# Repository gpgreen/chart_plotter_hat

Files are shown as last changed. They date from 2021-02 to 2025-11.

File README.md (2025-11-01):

# Chart Plotter Hat

KiCad design for Raspberry Pi Hat. Provides power and switch on/off
for the board. A total of 1.2A is provided for use by the
RaspberryPi. Also some connectors for GPS, barometric sensor, and ADC
measurements. Provides 12V power for a remote video board which is
switched at the same time as the Raspberry Pi. Contains a MCP2515 CAN
Controller and MCP2551 CAN transceiver for access to CAN bus. The
transceiver is isolated from the rest of the board. Has a
Qwiic connector that allows I2C
devices to be connected to the Raspberry Pi.

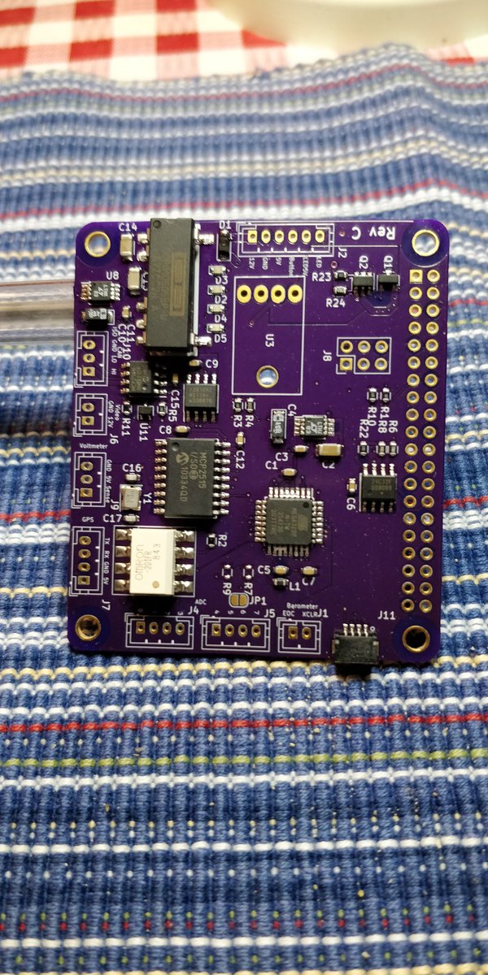
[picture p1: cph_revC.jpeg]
Finished


## Functions

1. Onboard ATmega328P
2. 1.2A DC power for RaspberryPi provided by
   AdaFruit MPM3610 5V Buck Converter Breakout
3. Video board power (12V) controlled by solid state relay G3VM-201FR
4. Serial Connector for GPS with 5V power, routed to Raspberry Pi Uart1.
5. 2 connectors with 4 pins each routed to adc pins on ATmega328P
6. Qwiic Connector, routed to I2C1 on Raspberry Pi
7. eeprom & power isolation as required by Raspberry Pi hat spec
8. Onboard 3.3V power for the ATmega328P.
9. SPI on ATmega328P routed to the Raspberry Pi SPI0 for communication
10. MCP2515 CAN network device, controlled by Raspberry Pi on SPI1
11. CAN is isolated to meet specs of NMEA 2000.
12. Connector for external voltmeter, or see 13.
13. Optional 12V voltage divider routed to ADC7 on the ATmega328P. This option is
    selected by a solder jumper.

## Firmware

There are 2 projects for the firmware. One is using `C`, the other `Rust`.
 - C firmware for the
onboard ATmega328P using avr-gcc and avr-libc.
 - Rust firmware.

The Rust firmware is still experimental. There are a number of
compiler bugs for the 8-bit AVR's yet.

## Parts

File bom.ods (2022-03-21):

D | Chart Plotter Hat
Rev | C
Design | /home/ggreen/cad/kicad/chart_plotter_hat/chart_plotter_hat.sch
Date
Components
ref | value | footprint | libsource | lib | part | description | sheetpath | names | tstamps | tstamp | datasheet | field | name
C1 | .1uF | Capacitors_SMD:C_0603 |  | Device | C | Unpolarized capacitor |  | / | / | 5FEBF281 | ~
C2 | 1uF | Capacitors_SMD:C_1206 |  | Device | C | Unpolarized capacitor |  | / | / | 5FE6DD6F | ~ | 25V | Voltage
C3 | .01uF | Capacitors_SMD:C_0603 |  | Device | C | Unpolarized capacitor |  | / | / | 5FE6EE51 | ~
C4 | 10uF | Capacitors_Tantalum_SMD:CP_Tantalum_Case-A_EIA-3216-18_Reflow |  | Device | CP | Polarized capacitor |  | / | / | 5FE95833 | ~
C5 | .1uF | Capacitors_SMD:C_0603 |  | Device | C | Unpolarized capacitor |  | / | / | 5FFED6E8 | ~
C6 | .1uF | Capacitors_SMD:C_0603 |  | Device | C | Unpolarized capacitor |  | / | / | 5FDB0A51 | ~
C7 | .1uF | Capacitors_SMD:C_0603 |  | Device | C | Unpolarized capacitor |  | / | / | 5FE38A21 | ~
C8 | .1uF | Capacitors_SMD:C_0603 |  | Device | C | Unpolarized capacitor |  | / | / | 0 | ~
C9 | .1uF | Capacitors_SMD:C_0603 |  | Device | C | Unpolarized capacitor |  | / | / | 615A87B3 | ~
C10 | 10uF | Capacitors_Tantalum_SMD:CP_Tantalum_Case-A_EIA-3216-18_Reflow |  | Device | CP | Polarized capacitor |  | / | / | 61359206 | ~
C11 | .01uF | Capacitors_SMD:C_0603 |  | Device | C | Unpolarized capacitor |  | / | / | 61313B3B | ~
C12 | .1uF | Capacitors_SMD:C_0603 |  | Device | C | Unpolarized capacitor |  | / | / | 609D50D2 | ~
C13 | 1uF | Capacitors_SMD:C_1206 |  | Device | C | Unpolarized capacitor |  | / | / | 614D291D | ~
C14 | 2.2uF | Capacitors_SMD:C_1206 |  | Device | C | Unpolarized capacitor |  | / | / | 61485000000000 | ~
C15 | .1uF | Capacitors_SMD:C_0603 |  | Device | C | Unpolarized capacitor |  | / | / | 609D9249 | ~
C16 | 18pF | Capacitors_SMD:C_0603 |  | Device | C | Unpolarized capacitor |  | / | / | 609DC300 | ~
C17 | 18pF | Capacitors_SMD:C_0603 |  | Device | C | Unpolarized capacitor |  | / | / | 609DCBED | ~
D1 | PMEG3020EH | Diodes_SMD:D_SOD-123 |  | Diode | PMEG3020EH | 30V, 2A ultra low Vf MEGA Schottky barrier rectifier, SOD-123F |  | / | / | 6019111C | https://assets.nexperia.com/documents/data-sheet/PMEG3020EH_EJ.pdf
D2 | RED | Diodes_SMD:D_0603 |  | Device | LED | Light emitting diode |  | / | / | 616837C9 | ~
D3 | RED | Diodes_SMD:D_0603 |  | Device | LED | Light emitting diode |  | / | / | 616BC4CF | ~
D4 | RED | Diodes_SMD:D_0603 |  | Device | LED | Light emitting diode |  | / | / | 616DB45B | ~
D5 | GRN | Diodes_SMD:D_0603 |  | Device | LED | Light emitting diode |  | / | / | 6180FD86 | ~
H1 | 3mm_Mounting_Hole | project_footprints:NPTH_3mm_ID |  | Mechanical | MountingHole | Mounting Hole without connection |  | / | / | 5834BC4A | ~
H2 | 3mm_Mounting_Hole | project_footprints:NPTH_3mm_ID |  | Mechanical | MountingHole | Mounting Hole without connection |  | / | / | 5834BCDF | ~ | 25V | Voltage
H3 | 3mm_Mounting_Hole | project_footprints:NPTH_3mm_ID |  | Mechanical | MountingHole | Mounting Hole without connection |  | / | / | 5834BD62 | ~
H4 | 3mm_Mounting_Hole | project_footprints:NPTH_3mm_ID |  | Mechanical | MountingHole | Mounting Hole without connection |  | / | / | 5834BDED | ~
J1 | JST PH | Connectors_JST:JST_PH_B2B-PH-K_02x2.00mm_Straight |  | Connector_Generic | Conn_01x02 | Generic connector, single row, 01x02, script generated (kicad-library-utils/schlib/autogen/connector/) |  | / | / | 61554C23 | ~
J2 | JST PH | Connectors_JST:JST_PH_B6B-PH-K_06x2.00mm_Straight |  | Connector_Generic | Conn_01x06 | Generic connector, single row, 01x06, script generated (kicad-library-utils/schlib/autogen/connector/) |  | / | / | 616B530A | ~
J3 | 40HAT | Connector_PinSocket_2.54mm:PinSocket_2x20_P2.54mm_Vertical |  | raspberrypi_hat | OX40HAT |  |  | / | / | 58DFC771 | ~
J4 | JST PH | Connectors_JST:JST_PH_B4B-PH-K_04x2.00mm_Straight |  | Connector_Generic | Conn_01x04 | Generic connector, single row, 01x04, script generated (kicad-library-utils/schlib/autogen/connector/) |  | / | / | 5FFD0767 | ~ | 25V | Voltage
J5 | JST PH | Connectors_JST:JST_PH_B4B-PH-K_04x2.00mm_Straight |  | Connector_Generic | Conn_01x04 | Generic connector, single row, 01x04, script generated (kicad-library-utils/schlib/autogen/connector/) |  | / | / | 5FFD2002 | ~
J6 | JST PH | Connectors_JST:JST_PH_B2B-PH-K_02x2.00mm_Straight |  | Connector_Generic | Conn_01x02 | Generic connector, single row, 01x02, script generated (kicad-library-utils/schlib/autogen/connector/) |  | / | / | 5FEFCBF8 | ~
J7 | JST PH | Connectors_JST:JST_PH_B4B-PH-K_04x2.00mm_Straight |  | Connector_Generic | Conn_01x04 | Generic connector, single row, 01x04, script generated (kicad-library-utils/schlib/autogen/connector/) |  | / | / | 5FD96B98 | ~
J8 | Conn_02x03_Odd_Even | Pin_Headers:Pin_Header_Straight_2x03_Pitch2.54mm |  | Connector_Generic | Conn_02x03_Odd_Even | Generic connector, double row, 02x03, odd/even pin numbering scheme (row 1 odd numbers, row 2 even numbers), script generated (kicad-library-utils/schlib/autogen/connector/) |  | / | / | 5FDFC5AF | ~
J9 | JST PH | Connectors_JST:JST_PH_B3B-PH-K_03x2.00mm_Straight |  | Connector_Generic | Conn_01x03 | Generic connector, single row, 01x03, script generated (kicad-library-utils/schlib/autogen/connector/) |  | / | / | 5FF77E36 | ~
J10 | JST PH | Connectors_JST:JST_PH_B3B-PH-K_03x2.00mm_Straight |  | Connector_Generic | Conn_01x03 | Generic connector, single row, 01x03, script generated (kicad-library-utils/schlib/autogen/connector/) |  | / | / | 617535000000000 | ~
J11 | Qwiic | Connectors_JST:JST_SH_BM04B-SRSS-TB_04x1.00mm_Straight |  | Connector_Generic | Conn_01x04 | Generic connector, single row, 01x04, script generated (kicad-library-utils/schlib/autogen/connector/) |  | / | / | 615837CF | ~
JP1 | SolderJumper_2_Open | CustomComponents:SolderJumper-2_P1.3mm_Open_RoundedPad1.0x1.5mm |  | Jumper | SolderJumper_2_Open | Solder Jumper, 2-pole, open |  | / | / | 601AB575 | ~
L1 | 10uH | Capacitors_SMD:C_0603 |  | Device | L_Small | Inductor, small symbol |  | / | / | 5FF4C159 | ~
Q1 | DMG2305UX | Package_TO_SOT_SMD:SOT-23 |  | raspberrypi_hat | DMG2305UX | Transistor P-MOSFET |  | / | / | 58E14EB1 | ~ | SML-D12U8WT86
Q2 | DMMT5401 | Package_TO_SOT_SMD:SOT-23-6 |  | raspberrypi_hat | DMMT5401 | PNP Matched Transistor Pair |  | / | / | 58E1538B | ~
R1 | 10K | Resistors_SMD:R_0603 |  | Device | R | Resistor |  | / | / | 5FEF7011
R2 | 1.6K | Resistors_SMD:R_0603 |  | Device | R | Resistor |  | / | / | 5FF8607A | ~
R3 | 390 | Resistors_SMD:R_0603 |  | Device | R | Resistor |  | / | / | 616854F3 | ~
R4 | 220 | Resistors_SMD:R_0603 |  | Device | R | Resistor |  | / | / | 616BC4C9 | https://toshiba.semicon-storage.com/info/docget.jsp?did=12660&prodName=TLP3543
R5 | 390 | Resistors_SMD:R_0603 |  | Device | R | Resistor |  | / | / | 616DB455 | http://ww1.microchip.com/downloads/en/devicedoc/21667d.pdf
R6 | 3.9K | Resistors_SMD:R_0603 |  | Device | R | Resistor |  | / | / | 0 | ~
R7 | 39K | Resistors_SMD:R_0603 |  | Device | R | Resistor |  | / | / | 5FF886A6 | ~
R8 | 3.9K | Resistors_SMD:R_0603 |  | Device | R | Resistor |  | / | / | 0 | ~
R9 | 12K | Resistors_SMD:R_0603 |  | Device | R | Resistor |  | / | / | 5FF8821A | ~ | SML-D12FWT86
R10 | 10K | Resistors_SMD:R_0603 |  | Device | R | Resistor |  | / | / | 5FF805D9 | ~
R11 | 300 | Resistors_SMD:R_0603 |  | Device | R | Resistor |  | / | / | 61810910 | http://ww1.microchip.com/downloads/en/DeviceDoc/ATmega328_P%20AVR%20MCU%20with%20picoPower%20Technology%20Data%20Sheet%2040001984A.pdf
R22 | 10K | Resistors_SMD:R_0603 |  | Device | R | Resistor |  | / | / | 58E19E51 | ~
R23 | 10K | Resistors_SMD:R_0603 |  | Device | R | Resistor |  | / | / | 0 | ~
R24 | 47K | Resistors_SMD:R_0603 |  | Device | R | Resistor |  | / | / | 58E158A1 | ~
U1 | ATmega328P-AU | Housings_QFP:TQFP-32_7x7mm_Pitch0.8mm |  | MCU_Microchip_ATmega | ATmega328P-AU | 20MHz, 32kB Flash, 2kB SRAM, 1kB EEPROM, TQFP-32 |  | / | / | 5FD67BE6 | http://ww1.microchip.com/downloads/en/DeviceDoc/ATmega328_P%20AVR%20MCU%20with%20picoPower%20Technology%20Data%20Sheet%2040001984A.pdf
U2 | CAT24C32 | Package_SOIC:SOIC-8_3.9x4.9mm_P1.27mm |  | raspberrypi_hat | CAT24C32 | I2C Serial EEPROM 32Kb |  | / | / | 58E1713F | ~
U3 | MPM3610-5.0-adafruit | CustomComponents:Adafruit_MPM3610 |  | adafruit | MPM3610-adafruit |  |  | / | / | 5FD6743F | ~
U4 | LT1762EMS8-3.3 | Housings_SSOP:MSOP-8_3x3mm_Pitch0.65mm |  | Regulator_Linear | LT1762 | 150mA, Adjustable, Low Noise, Micropower LDO Regulator, MSOP-8 |  | / | / | 5FE414E2 | https://www.analog.com/media/en/technical-documentation/data-sheets/LT1762.pdf
U5 | G3VM-201FR | Housings_DIP:DIP-8_W8.89mm_SMDSocket_LongPads |  | CustomComponents | G3VM-201FR | Photo MOSFET optically coupled, ON 4A, 50mohm, OFF state 20V, Isolation 2500 VRMS, DIP-6 |  | / | / | 5FEC1F34 | https://toshiba.semicon-storage.com/info/docget.jsp?did=12660&prodName=TLP3543
U6 | MCP2515-xSO | Housings_SOIC:SOIC-18W_7.5x11.6mm_Pitch1.27mm |  | Interface_CAN_LIN | MCP2515-xSO | Stand-Alone CAN Controller with SPI Interface, SOIC-18 |  | / | / | 60A70B0A | http://ww1.microchip.com/downloads/en/DeviceDoc/21801e.pdf
U7 | MCP2551-I-SN | Housings_SOIC:SOIC-8_3.9x4.9mm_Pitch1.27mm |  | Interface_CAN_LIN | MCP2551-I-SN | High-Speed CAN Transceiver, 1Mbps, 5V supply, SOIC-8 |  | / | / | 608CD80B | http://ww1.microchip.com/downloads/en/devicedoc/21667d.pdf
U8 | LT1762EMS8-5 | Housings_SSOP:MSOP-8_3x3mm_Pitch0.65mm |  | CustomComponents | LT1762-MS8 | Low Noise LDO |  | / | / | 612AA917 | ~
U9 | ADuM1281CRZ | Housings_SOIC:SOIC-8_3.9x4.9mm_Pitch1.27mm |  | Isolator | ADuM1201BR | Dual-Channel Digital Isolator, 10Mbps 50ns, bidirectional communication, 3V/5V level translation, SOIC-8 |  | / | / | 61231790 | https://www.analog.com/static/imported-files/data_sheets/ADuM1200_1201.pdf
U10 | DCP010505BP-U | CustomComponents:DCP01B_SO_7_14 |  | CustomComponents | DCP01B |  |  | / | / | 61341169 | ~
U11 | VCAN26A2 | TO_SOT_Packages_SMD:SOT-323_SC-70 |  | CustomComponents | VCAN26A2 | Bidirectional Symmetrical Low Capacitance Dual-Line ESD Protection Diode |  | / | / | 613DD013 | https://www.vishay.com/docs/85894/vcan26a2-03g.pdf | 25V | Voltage
Y1 | 16MHz | Crystals:Crystal_SMD_TXC_7M-4pin_3.2x2.5mm |  | Device | Crystal_GND24_Small | Four pin crystal, GND on pins 2 and 4, small symbol |  | / | / | 6085E13C | ~

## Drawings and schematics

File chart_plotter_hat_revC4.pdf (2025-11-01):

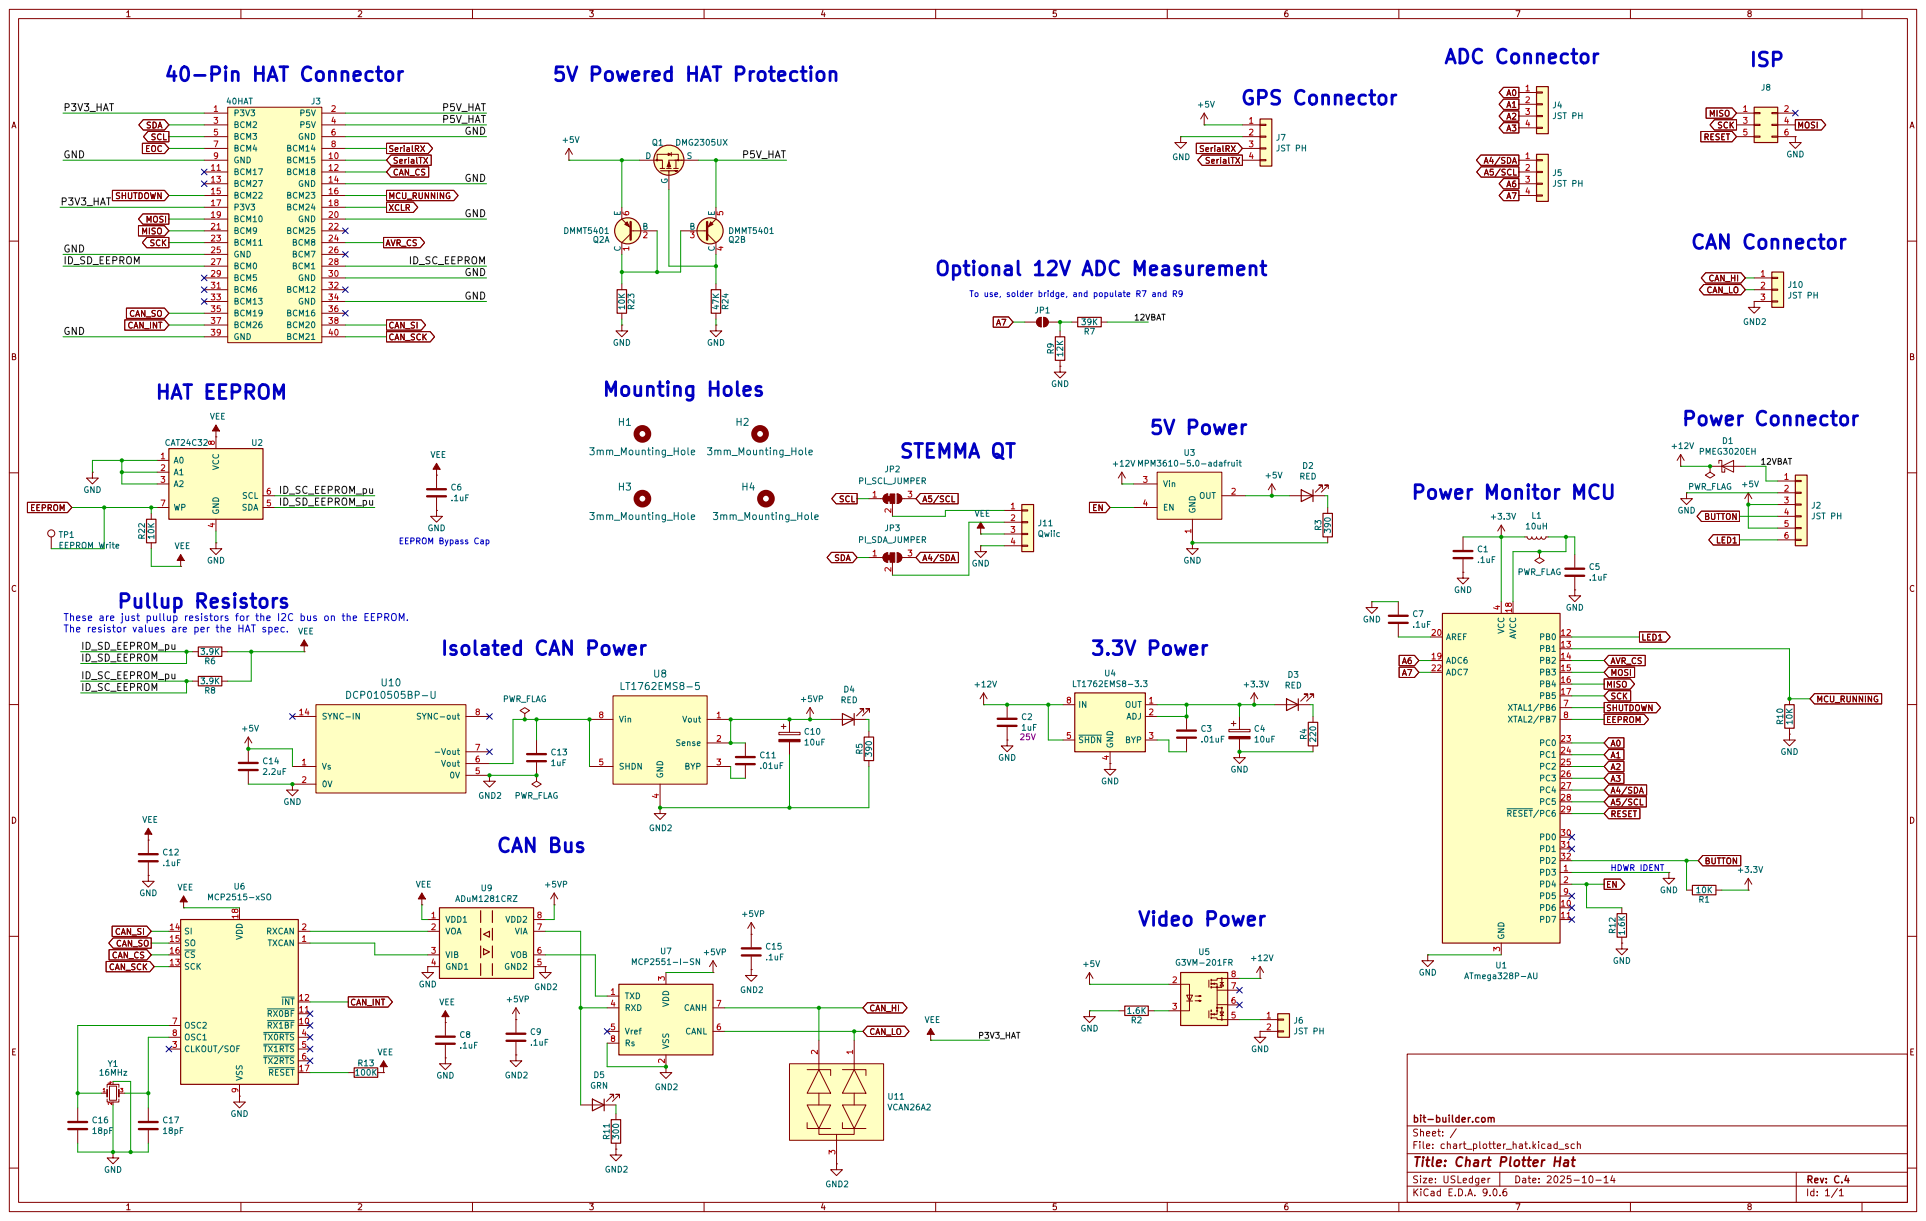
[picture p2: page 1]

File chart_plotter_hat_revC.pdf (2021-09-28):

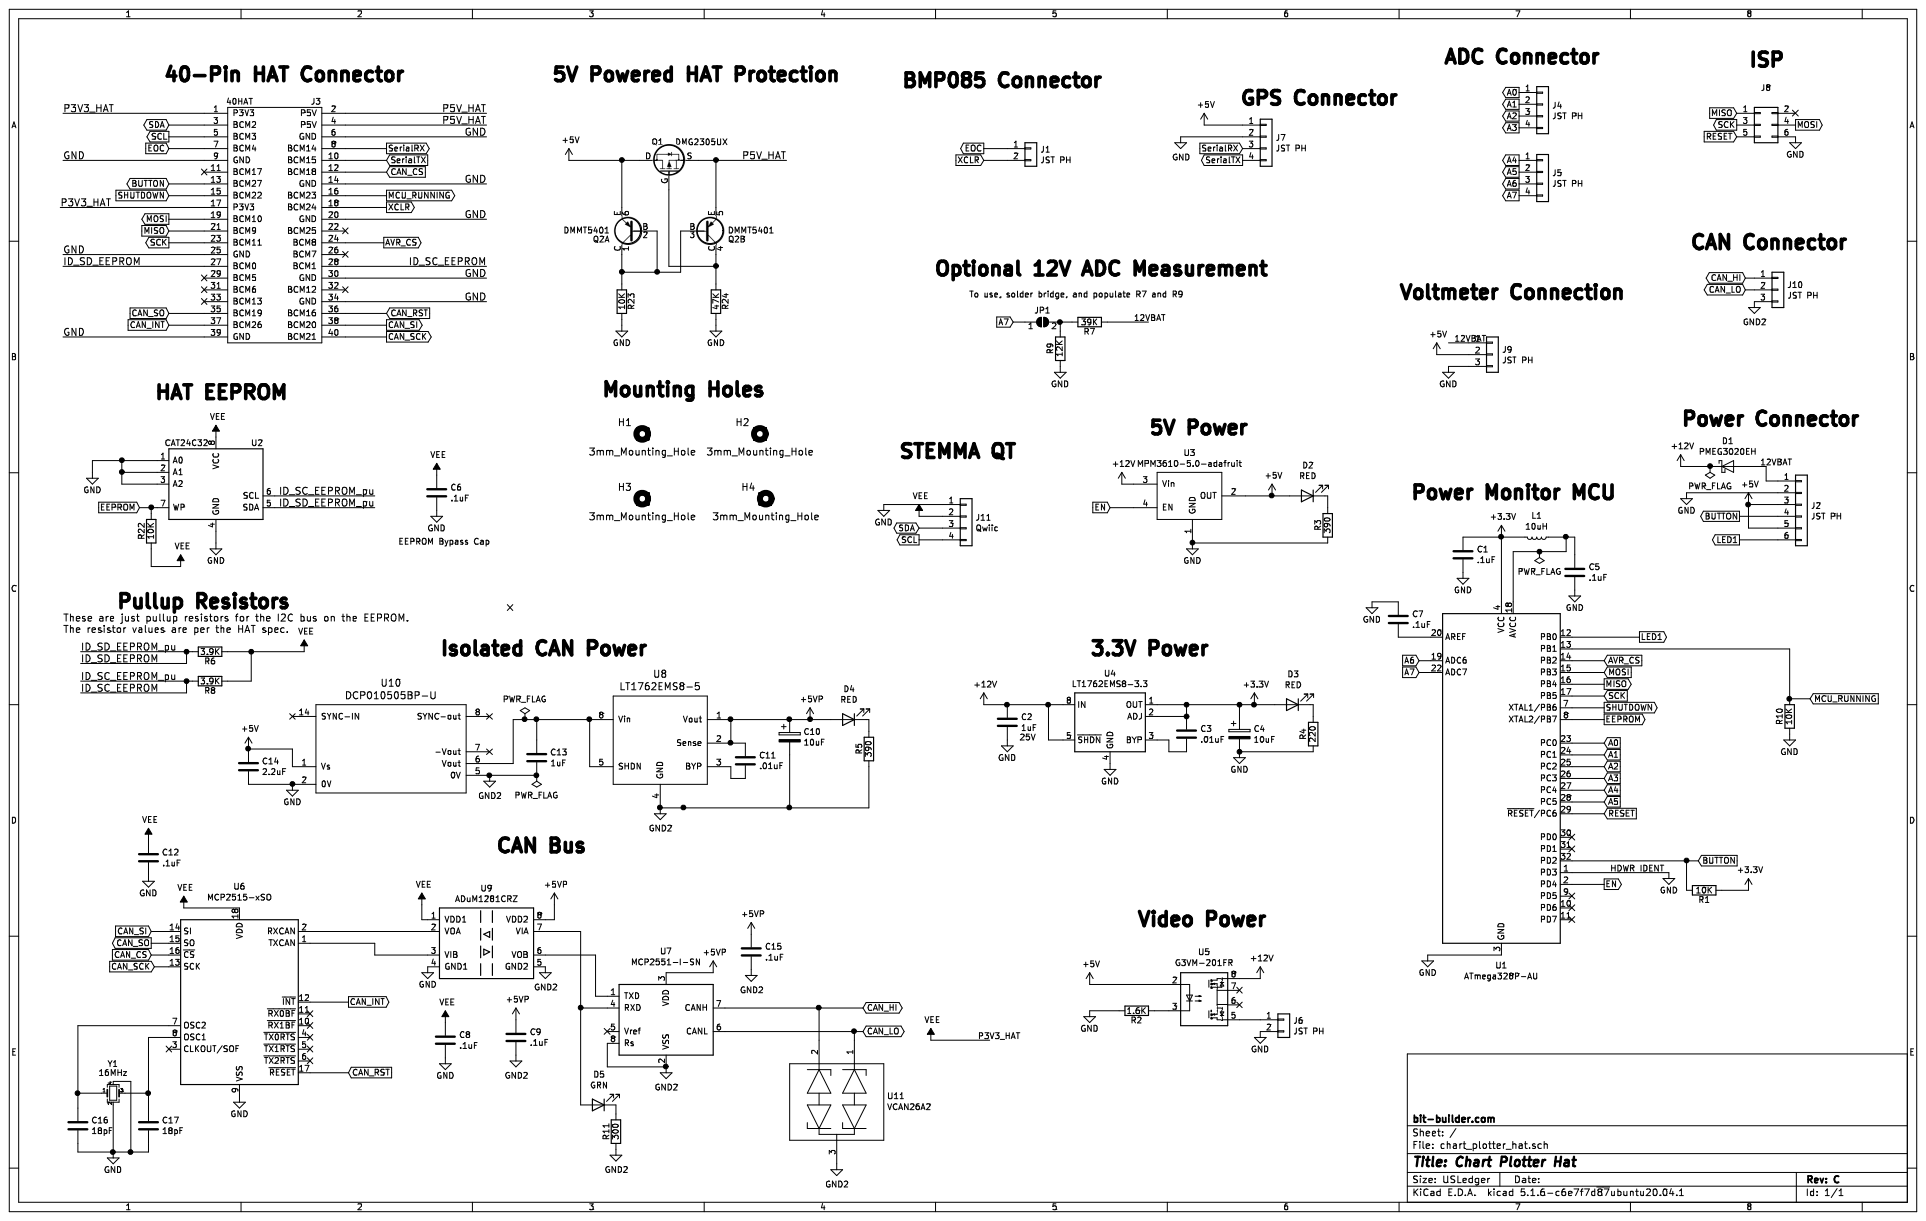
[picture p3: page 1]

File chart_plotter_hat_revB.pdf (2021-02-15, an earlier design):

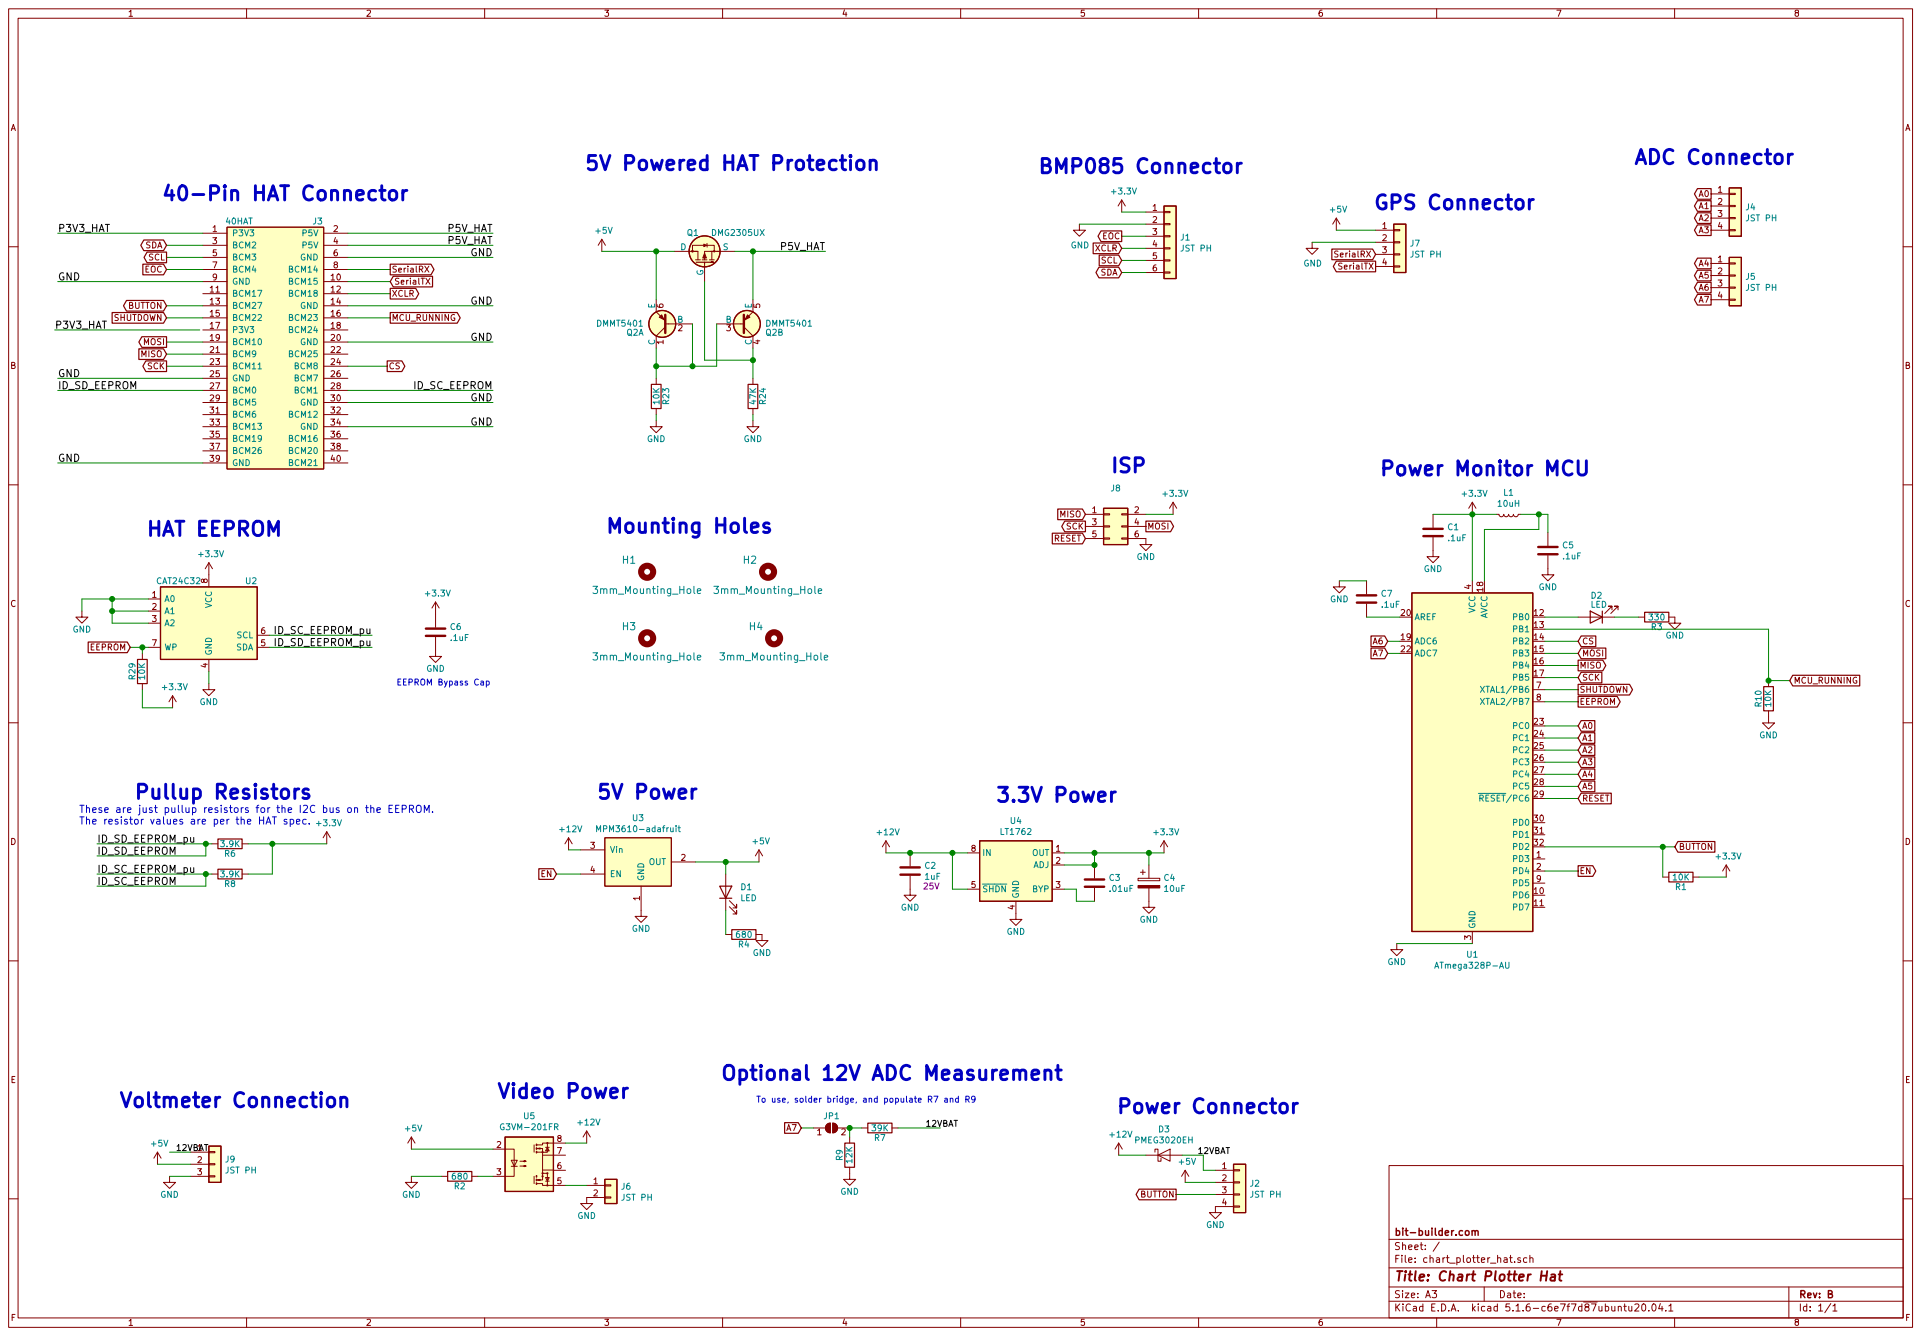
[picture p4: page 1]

A5 SCK MISO MOSI CS

These are just pullup resistors for the I2C bus on the EEPROM.
The resistor values are per the HAT spec.
ID_SD_EEPROM_pu
ID_SD_EEPROM
ID_SC_EEPROM_pu
ID_SC_EEPROM

1 OUT 2 Vin 3 EN 4 U3 MPM3610-adafruit 2

To use, solder bridge, and populate R7 and R9

File: chart_plotter_hat.sch Sheet: / bit-builder.com

Id: 1/1 Title: Chart Plotter Hat

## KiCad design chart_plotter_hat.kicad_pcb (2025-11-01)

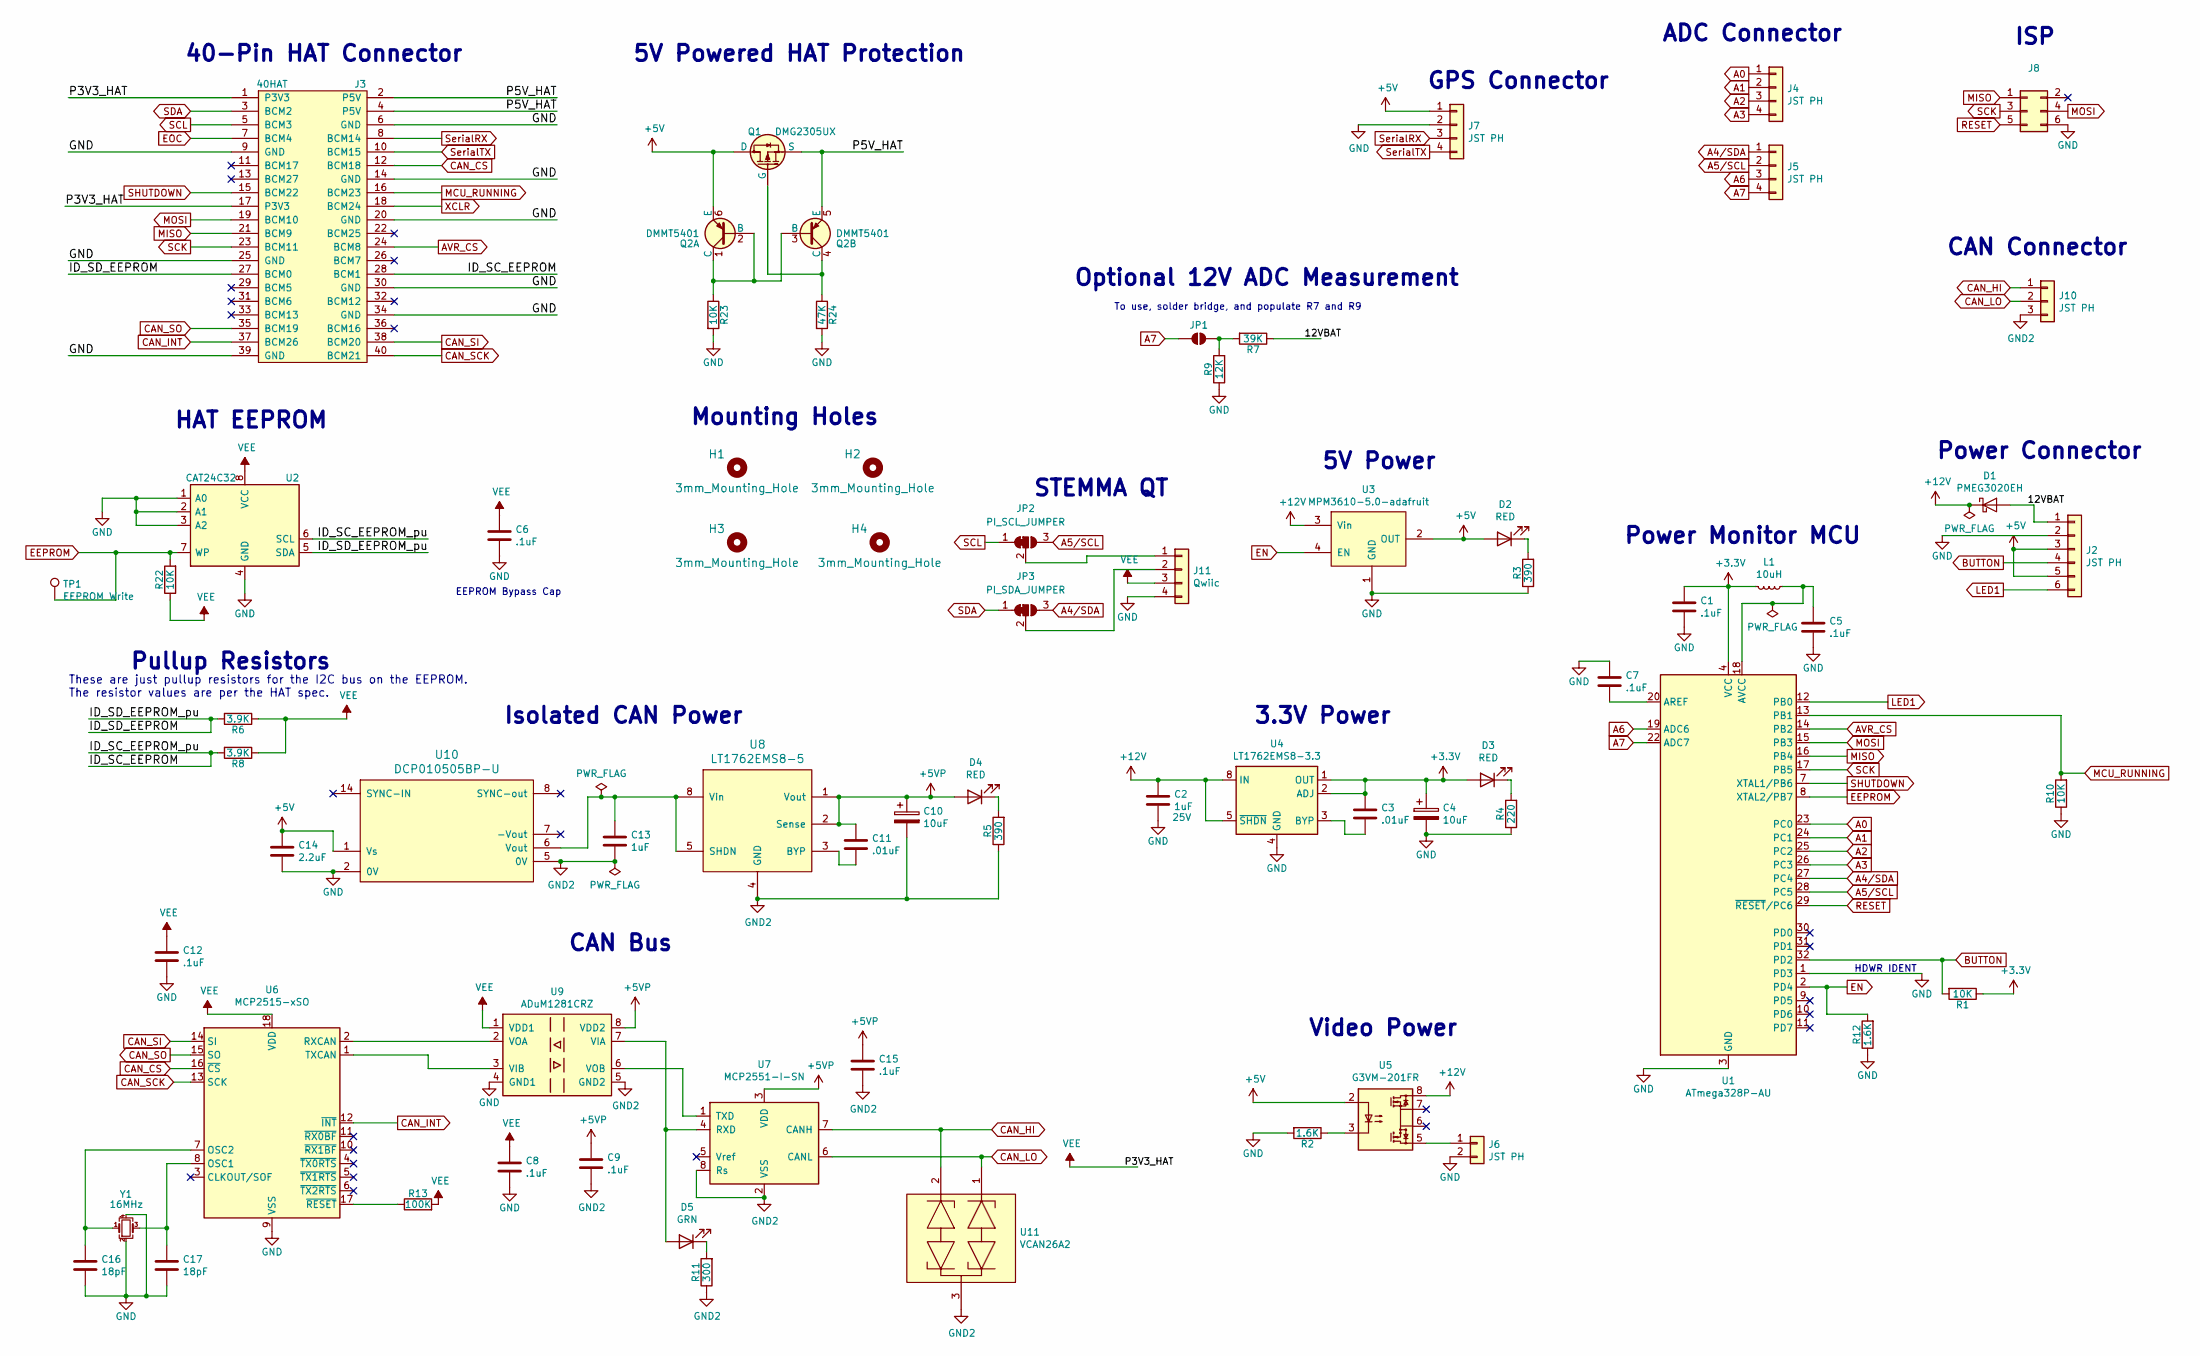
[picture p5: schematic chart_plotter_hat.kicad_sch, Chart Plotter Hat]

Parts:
C1, C5, C6, C7, C8, C9, C12, C15: .1uF; C_0603
C2: 1uF; C_1206; Voltage 25V
C3, C11: .01uF; C_0603
C4, C10: 10uF; CP_Tantalum_Case-A_EIA-3216-18_Reflow
C13: 1uF; C_1206
C14: 2.2uF; C_1206
C16, C17: 18pF; C_0603
D1: PMEG3020EH; D_SOD-123
D2, D3, D4: RED; D_0603
D5: GRN; D_0603
H1, H2, H3, H4: 3mm_Mounting_Hole; NPTH_3mm_ID
J2: JST PH; JST_PH_B6B-PH-K_06x2.00mm_Straight
J3: 40HAT; PinSocket_2x20_P2.54mm_Vertical
J4, J5, J7: JST PH; JST_PH_B4B-PH-K_04x2.00mm_Straight
J6: JST PH; JST_PH_B2B-PH-K_02x2.00mm_Straight
J8: Conn_02x03_Odd_Even; Pin_Header_Straight_2x03_Pitch2.54mm
J10: JST PH; JST_PH_B3B-PH-K_03x2.00mm_Straight
J11: Qwiic; JST_SH_BM04B-SRSS-TB_04x1.00mm_Straight
JP1: SolderJumper_2_Open; SolderJumper-2_P1.3mm_Open_RoundedPad1.0x1.5mm
JP2: PI_SCL_JUMPER; SolderJumper-3_P1.3mm_Bridged2Bar12_Pad1.0x1.5mm
JP3: PI_SDA_JUMPER; SolderJumper-3_P1.3mm_Bridged2Bar12_Pad1.0x1.5mm
L1: 10uH; C_0603
Q1: DMG2305UX; SOT-23
Q2: DMMT5401; SOT-23-6
R1, R10, R22, R23: 10K; R_0603
R2, R12: 1.6K; R_0603
R3, R5: 390; R_0603
R4: 220; R_0603
R6, R8: 3.9K; R_0603
R7: 39K; R_0603
R9: 12K; R_0603
R11: 300; R_0603
R13: 100K; R_0603
R24: 47K; R_0603
TP1: EEPROM Write; Measurement_Point_Square-SMD-Pad_Small
U1: ATmega328P-AU; TQFP-32_7x7mm_Pitch0.8mm
U2: CAT24C32; SOIC-8_3.9x4.9mm_P1.27mm
U3: MPM3610-5.0-adafruit; Adafruit_MPM3610
U4: LT1762EMS8-3.3; MSOP-8_3x3mm_Pitch0.65mm
U5: G3VM-201FR; DIP-8_W8.89mm_SMDSocket_LongPads
U6: MCP2515-xSO; SOIC-18W_7.5x11.6mm_Pitch1.27mm
U7: MCP2551-I-SN; SOIC-8_3.9x4.9mm_Pitch1.27mm
U8: LT1762EMS8-5; MSOP-8_3x3mm_Pitch0.65mm
U9: ADuM1281CRZ; SOIC-8_3.9x4.9mm_Pitch1.27mm
U10: DCP010505BP-U; DCP01B_SO_7_14
U11: VCAN26A2; SOT-323_SC-70
Y1: 16MHz; Crystal_SMD_TXC_7M-4pin_3.2x2.5mm

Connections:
+3.3V: C1.1, C3.1, C4.1, D3.2 (A), L1.2, R1.1, U1.4 (VCC), U1.6 (VCC), U4.1 (OUT), U4.2 (ADJ)
+5V: C14.1, D2.2 (A), J2.3, J2.5, J7.1, Q1.3 (D), Q2.6 (E), U3.2 (OUT), U5.2, U10.1 (Vs)
+5VP: C9.1, C10.1, C11.1, C15.1, D4.2 (A), U7.3 (VDD), U8.1 (Vout), U8.2 (Sense), U9.8 (VDD2)
+12V: C2.1, D1.1 (K), U3.3 (Vin), U4.5 (~SHDN), U4.8 (IN), U5.8
/12VBAT: D1.2 (A), J2.1, R7.1
/ID_SC_EEPROM: J3.28 (BCM1), R8.2, U2.6 (SCL)
/ID_SD_EEPROM: J3.27 (BCM0), R6.2, U2.5 (SDA)
/P5V_HAT: J3.2 (P5V), J3.4 (P5V), Q1.2 (S), Q2.5 (E)
A0: J4.1, U1.23 (PC0)
A1: J4.2, U1.24 (PC1)
A2: J4.3, U1.25 (PC2)
A3: J4.4, U1.26 (PC3)
A4/SDA: J5.1, JP3.3 (B), U1.27 (PC4)
A5/SCL: J5.2, JP2.3 (B), U1.28 (PC5)
A6: J5.3, U1.19 (ADC6)
A7: J5.4, JP1.1 (A), U1.22 (ADC7)
AVR_CS: J3.24 (BCM8), U1.14 (PB2)
BUTTON: J2.4, R1.2, U1.32 (PD2)
CAN_CS: J3.12 (BCM18), U6.16 (~CS)
CAN_HI: J10.1, U7.7 (CANH), U11.2
CAN_INT: J3.37 (BCM26), U6.12 (~INT)
CAN_LO: J10.2, U7.6 (CANL), U11.1
CAN_SCK: J3.40 (BCM21), U6.13 (SCK)
CAN_SI: J3.38 (BCM20), U6.14 (SI)
CAN_SO: J3.35 (BCM19), U6.15 (SO)
EEPROM: R22.2, TP1.1, U1.8 (XTAL2/PB7), U2.7 (WP)
EN: R12.2, U1.2 (PD4), U3.4 (EN)
EOC: J3.7 (BCM4)
GND: C1.2, C2.2, C4.2, C5.2, C6.2, C7.1, C8.2, C12.2, C14.2, C16.2, C17.2, J2.2, J3.6 (GND), J3.9 (GND), J3.14 (GND), J3.20 (GND), J3.25 (GND), J3.30 (GND), J3.34 (GND), J3.39 (GND), J6.2, J7.2, J8.6, J11.4, R2.2, R3.1, R4.1, R9.1, R10.1, R12.1, R23.2, R24.2, U1.1 (PD3), U1.3 (GND), U1.5 (GND), U1.21 (GND), U2.1 (A0), U2.2 (A1), U2.3 (A2), U2.4 (GND), U3.1 (GND), U4.4 (GND), U6.9 (VSS), U9.4 (GND1), U10.2 (0V), Y1.2, Y1.4
GND2: C9.2, C10.2, C13.2, C15.2, J10.3, R5.1, R11.1, U7.2 (VSS), U7.8 (Rs), U8.4 (GND), U9.5 (GND2), U10.5 (0V), U11.3
LED1: J2.6, U1.12 (PB0)
MCU_RUNNING: J3.16 (BCM23), R10.2, U1.13 (PB1)
MISO: J3.21 (BCM9), J8.1, U1.16 (PB4)
MOSI: J3.19 (BCM10), J8.4, U1.15 (PB3)
unnamed: D2.1 (K), R3.2
unnamed: D3.1 (K), R4.2
unnamed: D4.1 (K), R5.2
unnamed: D5.2 (A), U7.4 (RXD), U9.7 (VIA)
unnamed: D5.1 (K), R11.2
unnamed: J6.1, U5.5
unnamed: J11.1, JP2.2 (C)
unnamed: J11.2, JP3.2 (C)
unnamed: JP1.2 (B), R7.2, R9.2
unnamed: Q1.1 (G), Q2.4 (C), R24.1
unnamed: Q2.1 (C), Q2.2 (B), Q2.3 (B), R23.1
unnamed: R2.1, U5.3
unnamed: C7.2, U1.20 (AREF)
unnamed: C5.1, L1.1, U1.18 (AVCC)
unnamed: C3.2, U4.3 (BYP)
unnamed: C17.1, U6.8 (OSC1), Y1.3
unnamed: C16.1, U6.7 (OSC2), Y1.1
unnamed: U6.2 (RXCAN), U9.2 (VOA)
unnamed: U6.1 (TXCAN), U9.3 (VIB)
unnamed: R13.1, U6.17 (~RESET)
unnamed: U7.1 (TXD), U9.6 (VOB)
unnamed: C11.2, U8.3 (BYP)
unnamed: C13.1, U8.5 (SHDN), U8.8 (Vin), U10.6 (Vout)
RESET: J8.5, U1.29 (~RESET/PC6)
SCK: J3.23 (BCM11), J8.3, U1.17 (PB5)
SCL: J3.5 (BCM3), JP2.1 (A)
SDA: J3.3 (BCM2), JP3.1 (A)
SHUTDOWN: J3.15 (BCM22), U1.7 (XTAL1/PB6)
SerialRX: J3.8 (BCM14), J7.3
SerialTX: J3.10 (BCM15), J7.4
VEE: C6.1, C8.1, C12.1, J3.1 (P3V3), J3.17 (P3V3), J11.3, R6.1, R8.1, R13.2, R22.1, U2.8 (VCC), U6.18 (VDD), U9.1 (VDD1)
XCLR: J3.18 (BCM24)

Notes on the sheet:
3.3V Power
HAT EEPROM
5V Power
CAN Bus
These are just pullup resistors for the I2C bus on the EEPROM. The resistor values are per the HAT spec.
EEPROM Bypass Cap
Mounting Holes
To use, solder bridge, and populate R7 and R9
40-Pin HAT Connector
GPS Connector
Optional 12V ADC Measurement
Video Power
ADC Connector
5V Powered HAT Protection
Pullup Resistors
ISP
STEMMA QT
Isolated CAN Power
CAN Connector
Power Monitor MCU
HDWR IDENT
Power Connector

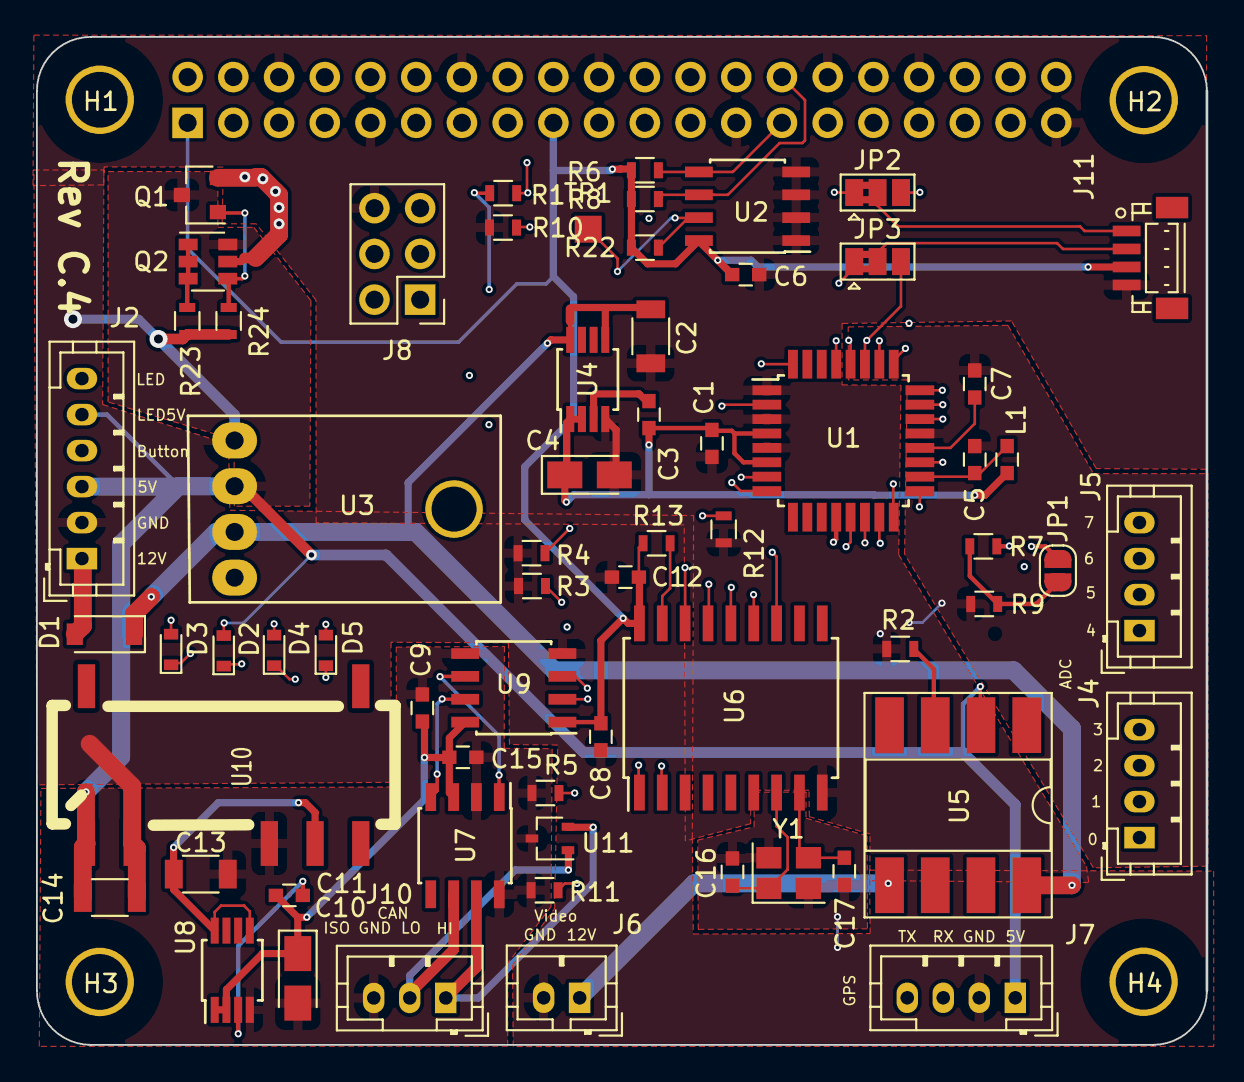
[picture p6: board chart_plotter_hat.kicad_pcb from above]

Board: 4 copper layers, 65.0 x 56.0 mm, 70 parts (1 on the bottom side), 64 nets.

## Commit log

2020-12-15 many changes
    [chart_plotter_hat.kicad_pcb, chart_plotter_hat.sch]
2020-12-15 Changed SS relay to a G3VM-201FR
    [chart_plotter_hat.kicad_pcb, chart_plotter_hat.sch]
2020-12-16 Changed footprints to non-solder
    changed headers to JST-PH connectors
    changed mask clearance
    Connected EOC
    [chart_plotter_hat.kicad_pcb, chart_plotter_hat.sch]
2020-12-18 MCU_RUNNING was connected to P3.3V on header
    Moved MCU_RUNNING to a gpio pin
    [chart_plotter_hat.kicad_pcb, chart_plotter_hat.sch]
2020-12-19 Initial Layout after adding mcp2515
    [chart_plotter_hat.kicad_pcb, chart_plotter_hat.sch]
2020-12-19 Using buffer chips instead of fet
    [chart_plotter_hat.kicad_pcb, chart_plotter_hat.sch]
2020-12-28 Updated layout using mcp2515 and buffers
    [chart_plotter_hat.kicad_pcb, chart_plotter_hat.sch]
2020-12-28 Added README and board graphic
2020-12-29 Added pulldown resistor to MCU_RUNNING
    [chart_plotter_hat.kicad_pcb, chart_plotter_hat.sch]
2020-12-29 Added pulldown R10 on MCU_RUNNING
    [chart_plotter_hat.kicad_pcb, chart_plotter_hat.sch]
2021-01-02 Fixed relay net
    [chart_plotter_hat.kicad_pcb, chart_plotter_hat.sch]
2021-01-02 Fixed relay wiring
    [chart_plotter_hat.kicad_pcb, chart_plotter_hat.sch]
2021-01-02 Updated board pix
2021-01-02 Moved R2 resistor to ground side of relay circuit
    [chart_plotter_hat.kicad_pcb, chart_plotter_hat.sch]
2021-01-02 Moved second led to MISO instead of shutdown
    Cleaned up some via's
    [chart_plotter_hat.kicad_pcb, chart_plotter_hat.sch]
2021-01-03 Redid relay wiring
    [chart_plotter_hat.kicad_pcb, chart_plotter_hat.sch]
2021-01-04 Added voltmeter connection
    Added reverse polarity protection diode
    Moved non-power LED to it's own pin
    Added R5, SHUTDOWN pull-down resistor
    [chart_plotter_hat.kicad_pcb, chart_plotter_hat.sch]
2021-01-04 Added Inductor to AVCC
    Added optional 12VBAT adc on A7
    Changed P5V label to +5V
    [chart_plotter_hat.kicad_pcb, chart_plotter_hat.sch]
2021-01-04 Added pdf of original release
    [chart_plotter_hat.sch]
2021-01-04 Added ADC ground plane
    [chart_plotter_hat.kicad_pcb]
2021-01-06 Moved CS to PD3, MCU_RUNNING to PB1
    Renamed SS to CS
    [chart_plotter_hat.kicad_pcb, chart_plotter_hat.sch]
2021-01-07 Removed pull down on SHUTDOWN, not needed
    [chart_plotter_hat.kicad_pcb, chart_plotter_hat.sch]
2021-01-10 Routed BUTTON to the Pi also
    [chart_plotter_hat.kicad_pcb, chart_plotter_hat.sch]
2021-01-16 Removed Jumper2, don't need
    [chart_plotter_hat.kicad_pcb, chart_plotter_hat.sch]
2021-02-15 Referenced rust firmware project
    Updated resistor values
    [chart_plotter_hat.sch]
2021-04-10 Updated from rev B
    [chart_plotter_hat.kicad_pcb, chart_plotter_hat.sch]
2021-04-10 First pass at layout
    [chart_plotter_hat.kicad_pcb, chart_plotter_hat.sch]
2021-04-12 Fixed 3.3aux switch and mounting hole sizes
    [chart_plotter_hat.kicad_pcb, chart_plotter_hat.sch]
2021-04-19 Added CAN_RST pull-ups
    [bom.ods, chart_plotter_hat.kicad_pcb, chart_plotter_hat.sch]
2021-04-24 Crystal was miswired
    Replaced schematic symbol for Y1
    Rewired Y1 in pcb
    [chart_plotter_hat.kicad_pcb, chart_plotter_hat.sch]
2021-08-15 Added optical isolation in CAN
    [chart_plotter_hat.kicad_pcb, chart_plotter_hat.sch]
2021-08-21 Redid CAN isolation, removed level shifter
    [chart_plotter_hat.kicad_pcb, chart_plotter_hat.sch]
2021-08-25 Updated README
    Created pdf of schematic, updated board graphic
    [chart_plotter_hat.kicad_pcb, chart_plotter_hat.sch]
2021-09-06 Added power isolation to CAN
    TVS added to CAN output
    DCP01B used for power isolation from board
    Another LT1762 used for CAN isolation power
    Removed pull-ups from CAN controller, should be controlled by Pi
    Added LED's for hat pwr, pi pwr, CAN isolation pwr, and CAN Rx
    Reordered connections on Power connector
    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
    [chart_plotter_hat.kicad_pcb, chart_plotter_hat.sch]
2021-09-08 Renamed some resistors
    Changed resistor value from 180 to 220, to match inventory
    [bom.ods, chart_plotter_hat.kicad_pcb, chart_plotter_hat.sch]
2021-09-08 Updated schematic pdf
    Changed drawing size to US Ledger, instead of A3
    [chart_plotter_hat.sch]
2021-09-08 Fixed bom to match schematic
    [bom.ods]
2021-09-17 Added DS1307 RTC
    Added coin cell battery holder
    updated bom
    [bom.ods, chart_plotter_hat.kicad_pcb, chart_plotter_hat.sch]
2021-09-18 Removed DS1307, (Not avail), added STEMMA QT conx
    can connect an adafruit breakout board for RTC instead
    [bom.ods, chart_plotter_hat.kicad_pcb, chart_plotter_hat.sch]
2021-09-28 Removed 6 pin J1, replaced with 2 pin J1
    barometer databus now goes through qwiic connector, only
    interrupt lines are in J1
    [bom.ods, chart_plotter_hat.kicad_pcb, chart_plotter_hat.sch]
2022-03-21 updated board.png and bom.ods
    [bom.ods]
2022-06-29 Added R12 pull-down to EN, jumper for eeprom write
    [chart_plotter_hat.kicad_pcb, chart_plotter_hat.sch]
2022-06-30 Added pullup on CAN RST, removed jumper on EEPROM write
    [chart_plotter_hat.kicad_pcb, chart_plotter_hat.sch]
2022-07-01 Removed pullup on CANRST, connected to 3.3V instead
    [chart_plotter_hat.kicad_pcb, chart_plotter_hat.sch]
2022-07-02 Added resistor between 3.3 and CAN RST
    [chart_plotter_hat.kicad_pcb, chart_plotter_hat.sch]
2022-07-22 qwik pcb connections were backwards, fixed
    [chart_plotter_hat.kicad_pcb, chart_plotter_hat.sch]
2025-10-14 Updated files for newer kicad
    [chart_plotter_hat.kicad_pcb, chart_plotter_hat.kicad_sch, chart_plotter_hat.sch]
2025-10-14 Added solder jumpers for SCL/SDA
    Removed BMP connector and associated routes
    Can now connect QWIK connector to Pi or Atmega via jumpers
    [chart_plotter_hat.kicad_pcb, chart_plotter_hat.kicad_sch]
2025-10-14 Removed voltmeter connector and traces
    Updated some trace routing
    [chart_plotter_hat.kicad_pcb, chart_plotter_hat.kicad_sch]
2025-11-01 Release of Rev C.4
    [chart_plotter_hat.kicad_pcb, chart_plotter_hat.kicad_sch]
